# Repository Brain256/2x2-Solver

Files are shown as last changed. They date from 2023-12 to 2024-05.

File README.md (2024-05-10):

# 2x2-Solver

https://www.youtube.com/shorts/pykEr9slMbM

This is a repository containing information on my Arduino 2x2 Rubik's cube solver 

## Hardware

This 2x2 solver utilizes my computer's webcam to gather data on the 2x2 Rubik's cube sides. It also utilizes an Arduino Uno microcontroller which is connected to a stepper motor and servo motor, which rotate the cube and flip the cube respectively. The program utilizes serial communication between my computer and the Arduino with a USB cable. 

## Design 

The 2x2 solver is made with a stepper motor attached to a cube holder allowing the cube to be rotated along the x-axis and uses a servo motor connected to a flipping arm that hits the cube from the bottom to flip the cube along the y-axis. To perform an actual turn of the 2x2 on just the top half, on the top part of the flipping arm there are 2 beams to hold the top half in place by turning the servo the opposite way to the flipping function while the bottom half is turned by the stepper motor. This combination of flipping and turning allows the 2x2 to be turned on any face.

## Program 

The 2x2 solver algorithm uses 2 separate programs, one on my computer in Python on VS code with another running on the Arduino. The Arduino program waits for serial signals given by the Python program on my computer and using those signals, adjusts the servo and stepper motors to perform turning, rotations, and flipping. The Python program is where the algorithm to solve the cube is created. The program first utilizes the Opencv library to create colour masks of the 4 pieces of every side to find the colour of each piece. The webcam colour information is stored in a 2d array, which represents the cube with each subarray containing the colour of each piece in each face of the cube. The 2d array representation of the cube is manipulated through the rotateCube function which moves the elements of the 2d array using specific Rubik's cube notation as can be seen here (https://ruwix.com/the-rubiks-cube/notation/). For simplicity, only 6 moves are implemented as the other moves can be performed from this set of 6 on the 2x2. The solution to solve the Rubik's cube is in the form of an array of these moves "R", "U", "F", "X", "Y", "Z". The Arduino is sent these individual characters and its program then performs different actions with the motors based on the move. 

## Algorithm to solve the cube

The algorithm to solve the cube is a Python version of the 2x2 speedcubing method Ortega as can be read here (https://kewbz.com/pages/2x2-ortega-method-full-algs-guide)

### First Face

The actual solution to solve the cube starts by solving the first face. The program utilizes a bfs approach to solve the first face performing every possible move in every possible order until it solves the first face. Due to the small size of the 2x2, this brute force is feasible not taking too much time to find a solution. The bfs function returns the sequence of moves to successfully solve the first face in the form of an array that will eventually store the whole solution. 

### Top face and last 2 layers

In order to solve the opposite face of the cube, a long series of if statements is used to check for each of the 7 possible cases and append its corresponding sequence of moves to solve that case to the solution array. Since the solutions utilize the full Rubik's cube notation, I created a function, parseToMachine, to convert the algorithm to all "R", "U", and "F" moves. Following finishing the top face, the 2 last layers are finished in a similar manner checking for all the cases and adding it on to the solution array. 

Once the array containing the solution is completed, it is split and each move is sent to the Arduino to physically turn the cube and solve it.

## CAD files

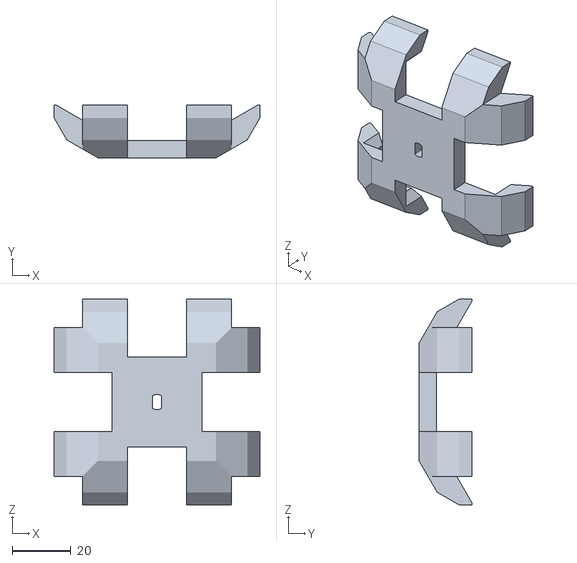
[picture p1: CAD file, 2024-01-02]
models/2x2_Bottom_Turner.stl
70.0 x 18.0 x 70.0

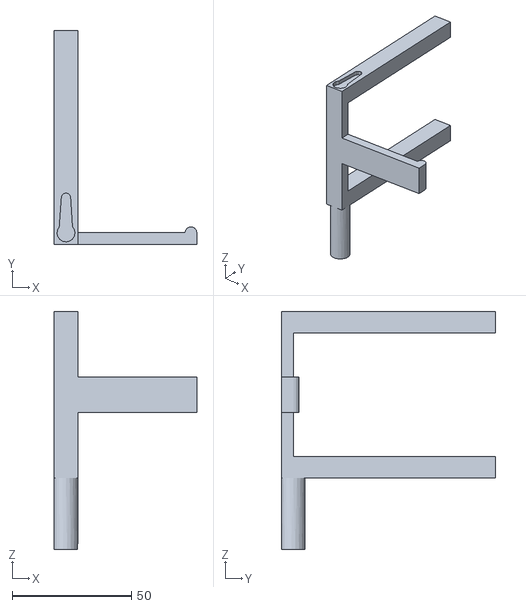
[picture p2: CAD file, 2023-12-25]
models/Solver_Attachment.stl
60.0 x 90.0 x 100.0

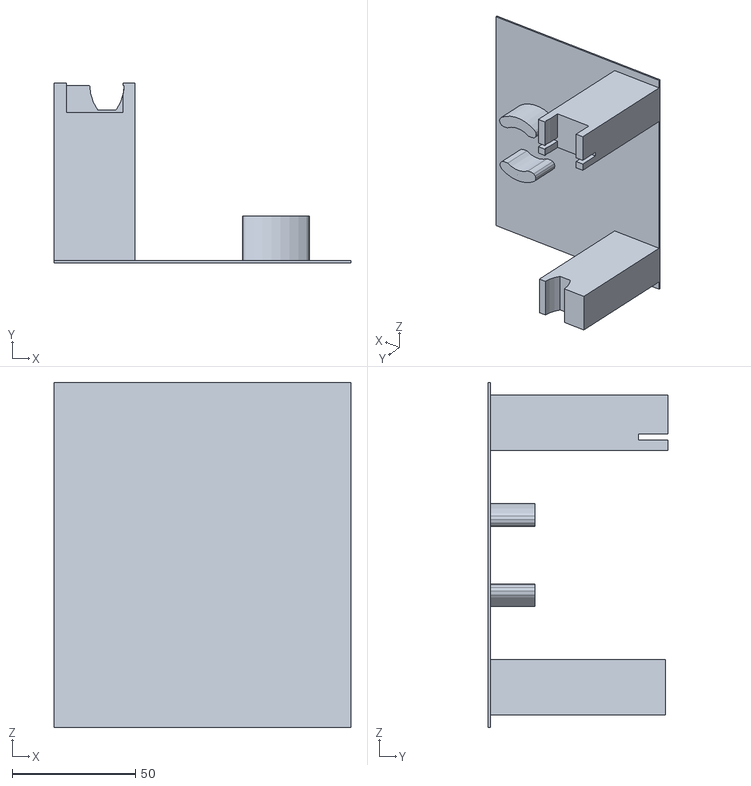
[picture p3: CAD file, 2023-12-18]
models/Solver_Base.stl
120.3 x 73.0 x 140.0

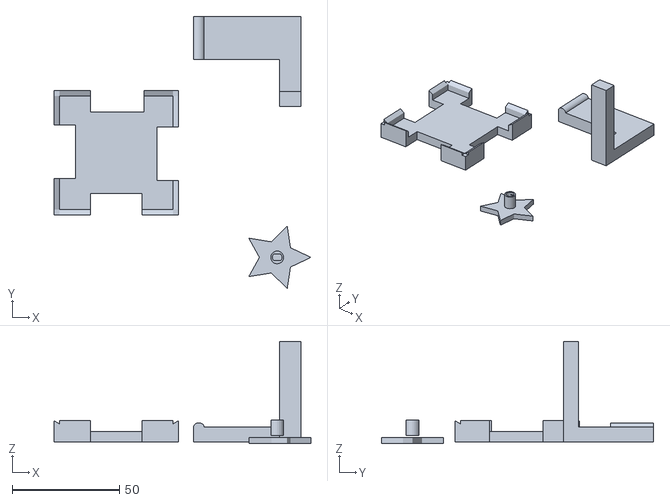
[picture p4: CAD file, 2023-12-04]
models/2x2Solver (4).stl
119.8 x 126.8 x 47.8

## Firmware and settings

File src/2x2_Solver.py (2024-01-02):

#import necessary libraries
import cv2
import time
import numpy as np
from collections import deque
import serial

def createFace(x, y, width):
    ROI = [x, y, x + width, y + width]
    
    ROI_tl = [ROI[0], ROI[1], ROI[0] + width/2, ROI[1] + width/2]
    ROI_tr = [ROI[0] + width/2, ROI[1], ROI[0] + width, ROI[1] + width/2]
    ROI_bl = [ROI[0], ROI[1] + width/2, ROI[0] + width/2, ROI[1] + width]
    ROI_br = [ROI[0] + width/2, ROI[1] + width/2, ROI[0] + width, ROI[1] + width]

    ROI_tl = list(map(int, ROI_tl))
    ROI_bl = list(map(int, ROI_bl))
    ROI_tr = list(map(int, ROI_tr))
    ROI_br = list(map(int, ROI_br))
    
    ROI = [ROI_tl, ROI_tr, ROI_bl, ROI_br]
    
    return ROI

def rotateCube(move, faces, times):

    faces = [face.copy() for face in faces]

    for i in range(times):   
        if move == "R":
            face_nums = [2]
            f = [1, 5, 3, 4]
            p1_index = 1
            p2_index = 3
            
            temp1 = faces[1][p1_index]
            temp2 = faces[1][p2_index]
            
            faces[1][p1_index] = faces[5][p1_index]
            faces[1][p2_index] = faces[5][p2_index]
            
            faces[5][p1_index] = faces[3][2]
            faces[5][p2_index] = faces[3][0]
            
            faces[3][2] = faces[4][p1_index]
            faces[3][0] = faces[4][p2_index]
            
            faces[4][p1_index] = temp1
            faces[4][p2_index] = temp2
            
        if move == "U":

            face_nums = [4]
            f = [1, 2, 3, 0]
            p1_index = 0
            p2_index = 1
            
            p1 = faces[f[0]][p1_index]
            p2 = faces[f[0]][p2_index]
            
            for i in range(3):
                faces[f[i]][p1_index] = faces[f[i+1]][p1_index]
                faces[f[i]][p2_index] = faces[f[i+1]][p2_index]
            
            faces[f[3]][p1_index] = p1
            faces[f[3]][p2_index] = p2
        
        if move == "F":
            face_nums = [1]
            
            temp1 = faces[4][2]
            temp2 = faces[4][3]
            
            faces[4][2] = faces[0][3]
            faces[4][3] = faces[0][1]
            
            faces[0][3] = faces[5][1]
            faces[0][1] = faces[5][0]
            
            faces[5][1] = faces[2][0]
            faces[5][0] = faces[2][2]
            
            faces[2][0] = temp1
            faces[2][2] = temp2

        if move == "X": 
            face_nums = [0, 2]
            
            f = [1, 5, 3, 4]
            
            p = faces[f[0]].copy()
            
            for i in range(3):
                if i == 2: 
                    faces[3][0] = faces[4][3]
                    faces[3][1] = faces[4][2]
                    faces[3][2] = faces[4][1]
                    faces[3][3] = faces[4][0]
                elif i + 1 == 2: 
                    faces[5][0] = faces[3][3]
                    faces[5][1] = faces[3][2]
                    faces[5][2] = faces[3][1]
                    faces[5][3] = faces[3][0]
                    
                else: 
                    faces[f[i]] = faces[f[i+1]].copy()
            
            faces[f[3]] = p

        if move == "Y": 
            face_nums = [4, 5]

            f = [1, 2, 3, 0]
            
            p = faces[f[0]].copy()
            
            for i in range(3):
                faces[f[i]] = faces[f[i+1]]
            
            faces[f[3]] = p

        if move == "Z": 
            face_nums = [1, 3]
            
            f = [2, 4, 0, 5]
            
            p = faces[f[0]].copy()

            for i in range(3):
                faces[f[i]][0] = faces[f[i+1]][2]
                faces[f[i]][1] = faces[f[i+1]][0]
                faces[f[i]][2] = faces[f[i+1]][3]
                faces[f[i]][3] = faces[f[i+1]][1]

            faces[f[3]][0] = p[2]
            faces[f[3]][1] = p[0]
            faces[f[3]][2] = p[3]
            faces[f[3]][3] = p[1]

            
        for face_num in face_nums: 
            if face_num == 3 or face_num == 0: 
                temp = faces[face_num][2]
                
                faces[face_num][2] = faces[face_num][0]
                faces[face_num][0] = faces[face_num][1]
                faces[face_num][1] = faces[face_num][3]
                faces[face_num][3] = temp

            else: 
                temp = faces[face_num][2]
                
                faces[face_num][2] = faces[face_num][3]
                faces[face_num][3] = faces[face_num][1]
                faces[face_num][1] = faces[face_num][0]
                faces[face_num][0] = temp

    return faces

def checkSolvedTB(faces): 

    for i, face in enumerate(faces): 
        if i == 4 or i == 5: 
            col = face[0]
            for piece in face: 
                if piece != col: 
                    return False

    return True

def checkSolvedRL(faces): 

    for i, face in enumerate(faces): 
        if i == 2 or i == 0: 
            col = face[0]
            for piece in face: 
                if piece != col: 
                    return False

    return True

def checkSolvedFB(faces): 

    for i, face in enumerate(faces): 
        if i == 3 or i == 1: 
            col = face[0]
            for piece in face: 
                if piece != col: 
                    return False

    return True

def checkSolved(faces): 

    for i, face in enumerate(faces): 
            col = face[0]
            for piece in face: 
                if piece != col: 
                    return False

    return True

def scramble(move_list, faces): 

    for move in move_list: 
        
        faces = rotateCube(move[0], faces, int(move[1]))

    return faces

def process(move_list): 

    for i in range(len(move_list)): 

        if len(move_list[i]) == 1: 
            move_list[i] += "1"

        if move_list[i][1] == "'": 
            move_list[i] = move_list[i][0] + "3"


def solveTB(queue):

    while len(queue) > 0:
        
        cur = queue.popleft()
        move_list = cur[0]
        faces = cur[1]

        #print(queue)

        if len(move_list) > 11:
            break

        print(move_list)
        
        faces = rotateCube(move_list[-1][0], faces, int(move_list[-1][1]))
        #print(faces)
        
        if checkSolved(faces) or checkSolvedTB(faces) or checkSolvedRL(faces) or checkSolvedFB(faces): 
            return move_list, faces

        for move in moves:
            for i in range(3):
                moveTemp = move_list.copy()
                if move != move_list[-1][0]:
                    moveTemp.append(move + str(i+1))
                    
                    queue.append([moveTemp, faces])

    return []

def solvePBL(result, cube): 
    if checkSolvedRL(cube): 
        #orient cube so solved faces are on top and bottom
        result.append("Z1")
        cube = rotateCube("Z", cube, 1)
    
    elif checkSolvedFB(cube):
        #orient cube so solved faces are on top and bottom
        result.append("X1")
        cube = rotateCube("X", cube, 1)

    algorithm = []
    #both layers solved
    if (cube[0][2] == cube[0][3] and cube[1][2] == cube[1][3] and cube[2][2] == cube[2][3] and cube[3][2] == cube[3][3]) and (cube[0][0] == cube[0][1] and cube[1][0] == cube[1][1] and cube[2][0] == cube[2][1] and cube[3][0] == cube[3][1]): 
        pass
    #bottom layer solved
    elif cube[0][2] == cube[0][3] and cube[1][2] == cube[1][3] and cube[2][2] == cube[2][3] and cube[3][2] == cube[3][3]: 
        #bar on top layer
        if cube[0][0] == cube[0][1] or cube[1][0] == cube[1][1] or cube[2][0] == cube[2][1] or cube[3][0] == cube[3][1]:
            
            if cube[1][0] == cube[1][1]: 
                result.append("Y1")
                cube = rotateCube("Y", cube, 1)
            elif cube[2][0] == cube[2][1]:
                result.append("Y2")
                cube = rotateCube("Y", cube, 2)
            elif cube[3][0] == cube[3][1]: 
                result.append("Y3")
                cube = rotateCube("Y", cube, 3)

            algorithm = "R U R' U' R' F R2 U' R' U' R U R' F'".split()
        else:
            algorithm = "F R U' R' U' R U R' F' R U R' U' R' F R F'".split()

    #top layer solved
    elif cube[0][0] == cube[0][1] and cube[1][0] == cube[1][1] and cube[2][0] == cube[2][1] and cube[3][0] == cube[3][1]: 
        #bar on bottom layer
        if cube[0][2] == cube[0][3] or cube[1][2] == cube[1][3] or cube[2][2] == cube[2][3] or cube[3][2] == cube[3][3]:
            if cube[1][2] == cube[1][3]: 
                result.append("Y1")
                cube = rotateCube("Y", cube, 1)
            elif cube[2][2] == cube[2][3]:
                result.append("Y2")
                cube = rotateCube("Y", cube, 2)
            elif cube[3][2] == cube[3][3]: 
                result.append("Y3")
                cube = rotateCube("Y", cube, 3)

            algorithm = "R' U R' U' R' F R2 U' R' U' R U R' F' R2".split()
        else:
            result.append("X2")
            cube = rotateCube("X", cube, 2)

            algorithm = "F R U' R' U' R U R' F' R U R' U' R' F R F'".split()
    #bars on both layers
    elif (cube[0][2] == cube[0][3] or cube[1][2] == cube[1][3] or cube[2][2] == cube[2][3] or cube[3][2] == cube[3][3]) and (cube[0][0] == cube[0][1] or cube[1][0] == cube[1][1] or cube[2][0] == cube[2][1] or cube[3][0] == cube[3][1]): 
        if cube[0][2] == cube[0][3]: 
            result.append("Y3")
            cube = rotateCube("Y", cube, 3)
        elif cube[2][2] == cube[2][3]:
            result.append("Y1")
            cube = rotateCube("Y", cube, 1)
        elif cube[3][2] == cube[3][3]: 
            result.append("Y2")
            cube = rotateCube("Y", cube, 2)

        if cube[0][0] == cube[0][1]: 
            result.append("U3")
            cube = rotateCube("U", cube, 3)
        elif cube[2][0] == cube[2][1]:
            result.append("U1")
            cube = rotateCube("U", cube, 1)
        elif cube[3][0] == cube[3][1]: 
            result.append("U2")
            cube = rotateCube("U", cube, 2)
        
        algorithm = "R2 U' F2 U2 R2 U' F2".split()

    #bar on bottom layer
    elif cube[0][2] == cube[0][3] or cube[1][2] == cube[1][3] or cube[2][2] == cube[2][3] or cube[3][2] == cube[3][3]: 
        result.append("Z2")
        cube = rotateCube("Z", cube, 2)

        if cube[0][0] == cube[0][1]: 
            result.append("Y3")
            cube = rotateCube("Y", cube, 3)
        elif cube[2][0] == cube[2][1]:
            result.append("Y1")
            cube = rotateCube("Y", cube, 1)
        elif cube[3][0] == cube[3][1]: 
            result.append("Y2")
            cube = rotateCube("Y", cube, 2)
        
        algorithm = "R U' R F2 R' U R'".split()

    #bar on top layer
    elif cube[0][0] == cube[0][1] or cube[1][0] == cube[1][1] or cube[2][0] == cube[2][1] or cube[3][0] == cube[3][1]: 
        if cube[0][0] == cube[0][1]: 
            result.append("Y3")
            cube = rotateCube("Y", cube, 3)
        elif cube[2][0] == cube[2][1]:
            result.append("Y1")
            cube = rotateCube("Y", cube, 1)
        elif cube[3][0] == cube[3][1]: 
            result.append("Y2")
            cube = rotateCube("Y", cube, 2)
        
        algorithm = "R U' R F2 R' U R'".split()

    else: 
        algorithm = "R2 F2 R2".split()

    process(algorithm)
    cube = scramble(algorithm, cube)
    result.extend(algorithm)

    #auf
    if not checkSolved(cube): 
        if cube[1][0] == cube[0][2]:
            result.append("U1")
            cube = rotateCube("U", cube, 1)
        elif cube[2][0] == cube[0][2]: 
            result.append("U2")
            cube = rotateCube("U", cube, 2)
        elif cube[3][0] == cube[0][2]: 
            result.append("U3")
            cube = rotateCube("U", cube, 3)

    return cube

def parseToMachine(moveList): #turns the generated solution into a solution that the robot can use since the robot can only use X, Y and D moves, assumes that the front of the cube is facing the flipper
    newMoves = []

    for move in moveList: 
        if move[0] == "R": 
            newMoves.extend(f"Y3 X1 D{move[1]} X3 Y1".split())
        elif move[0] == "U": 
            newMoves.extend(f"D{move[1]} Y{move[1]}".split())
        elif move[0] == "F": 
            newMoves.extend(f"X3 D{move[1]} X1".split())
        elif move[0] == "Z": 
            newMoves.extend(f"Y3 X{move[1]} Y1".split()) 
        else: 
            newMoves.append(move)
    
    print(newMoves)

    length = len(newMoves) - 1
    i = 0

    while i < length:
        if newMoves[i][0] == newMoves[i+1][0]:
            num = (int(newMoves[i][1]) + int(newMoves[i+1][1])) % 4

            if num == 0:
                newMoves.pop(i)
                newMoves.pop(i)
                length -= 2
                i -= 1
            else:
                newMoves.pop(i+1)
                newMoves[i] = newMoves[i][0] + str(num)
                length -= 1
                i -= 1

        i += 1


    return newMoves

    
moves = ["R", "U", "F"]
    

ROI_tl = createFace(220, 140, 200)[0]
ROI_tr = createFace(220, 140, 200)[1]
ROI_bl = createFace(220, 140, 200)[2]
ROI_br = createFace(220, 140, 200)[3]

#0 - Left, 1 - front, 2 - right, 3 - back, 4 - top, 5 - bottom
curFace = 0

face_left = createFace(10, 70, 50)
face_front = createFace(70, 70, 50)
face_right = createFace(130, 70, 50)
face_back = createFace(190, 70, 50)
face_top = createFace(70, 10, 50)
face_bottom = createFace(70, 130, 50)

faceDisplay = [face_left, face_front, face_right, face_back, face_top, face_bottom]
faceColours = [[], [], [], [], [], []]

colours = ["orange", "red", "green", "blue", "white", "yellow"]

#colour codes in BGR
colCodes = [
    (0, 165, 255),   # Orange
    (0, 0, 255),     # Red
    (0, 255, 0),     # Green
    (255, 0, 0),     # Blue
    (255, 255, 255), # White
    (0, 255, 255)    # Yellow
]

#0 for orange, 1 for red, 2 for green, 3 for blue, 4 for white, 5 for yellow
quadColours = [0, 0, 0, 0]

for i in range(6): 
    faceColours[i] = quadColours.copy()

startTime = 0
curTime = time.time()

cam = cv2.VideoCapture(0)

beginTime = False
sGenerated = False
result = []

ser = serial.Serial('COM5', 115200)

seq = [['Y1'], ['Y1'], ['Y1'], ['Y2', 'X1'], ['X2'], ['X1, Y2']]

#main loop
while True:
    
    #get an image from pi camera
    res, img = cam.read()

    if not beginTime: 
        startTime = time.time()
        beginTime = True 

    curTime = time.time()
        
    if curTime - startTime > 3:
        if curFace != 6:
            curFace += 1

            for move in seq[curFace-1]: 
                time.sleep(1)
                print(move)
                ser.write(move.encode())

                while True: 

                    data = ser.readline().decode('utf-8').rstrip()

                    if data == "done":
                        print("move finished")
                        break
                    
            startTime = time.time()
    
    if curFace != 6: 
    
        # convert from BGR to HSV
        img_hsv = cv2.cvtColor(img, cv2.COLOR_BGR2HSV)
        
        # orange mask
        lower_orange = np.array([7, 90, 172])
        upper_orange = np.array([16, 255, 255])

        o_mask = cv2.inRange(img_hsv, lower_orange, upper_orange)
        
        #create red mask
        lower_red = np.array([0, 110, 155])
        upper_red = np.array([6, 255, 255])
        
        r_mask = cv2.inRange(img_hsv, lower_red, upper_red)
        
        #create green mask
        lower_green = np.array([43, 0, 120])
        upper_green = np.array([88, 255, 255])

        g_mask = cv2.inRange(img_hsv, lower_green, upper_green)
        
        #create blue mask
        lower_blue = np.array([92, 120, 110])
        upper_blue = np.array([110, 255, 255])

        b_mask = cv2.inRange(img_hsv, lower_blue, upper_blue)
        #create white mask
        lower_white = np.array([0, 0, 120])
        upper_white = np.array([180, 50, 255])

        w_mask = cv2.inRange(img_hsv, lower_white, upper_white)
        
        #create yellow mask
        lower_yellow = np.array([16, 90, 160])
        upper_yellow = np.array([40, 255, 255])

        y_mask = cv2.inRange(img_hsv, lower_yellow, upper_yellow)
        
        #ORANGE
        o_cont_tl = cv2.findContours(o_mask[ROI_tl[1]:ROI_tl[3], ROI_tl[0]:ROI_tl[2]], cv2.RETR_EXTERNAL, cv2.CHAIN_APPROX_SIMPLE)[-2]
        o_cont_tr = cv2.findContours(o_mask[ROI_tr[1]:ROI_tr[3], ROI_tr[0]:ROI_tr[2]], cv2.RETR_EXTERNAL, cv2.CHAIN_APPROX_SIMPLE)[-2]
        o_cont_bl = cv2.findContours(o_mask[ROI_bl[1]:ROI_bl[3], ROI_bl[0]:ROI_bl[2]], cv2.RETR_EXTERNAL, cv2.CHAIN_APPROX_SIMPLE)[-2]
        o_cont_br = cv2.findContours(o_mask[ROI_br[1]:ROI_br[3], ROI_br[0]:ROI_br[2]], cv2.RETR_EXTERNAL, cv2.CHAIN_APPROX_SIMPLE)[-2]
        
        #RED
        r_cont_tl = cv2.findContours(r_mask[ROI_tl[1]:ROI_tl[3], ROI_tl[0]:ROI_tl[2]], cv2.RETR_EXTERNAL, cv2.CHAIN_APPROX_SIMPLE)[-2]
        r_cont_tr = cv2.findContours(r_mask[ROI_tr[1]:ROI_tr[3], ROI_tr[0]:ROI_tr[2]], cv2.RETR_EXTERNAL, cv2.CHAIN_APPROX_SIMPLE)[-2]
        r_cont_bl = cv2.findContours(r_mask[ROI_bl[1]:ROI_bl[3], ROI_bl[0]:ROI_bl[2]], cv2.RETR_EXTERNAL, cv2.CHAIN_APPROX_SIMPLE)[-2]
        r_cont_br = cv2.findContours(r_mask[ROI_br[1]:ROI_br[3], ROI_br[0]:ROI_br[2]], cv2.RETR_EXTERNAL, cv2.CHAIN_APPROX_SIMPLE)[-2]
        
        #GREEN
        g_cont_tl = cv2.findContours(g_mask[ROI_tl[1]:ROI_tl[3], ROI_tl[0]:ROI_tl[2]], cv2.RETR_EXTERNAL, cv2.CHAIN_APPROX_SIMPLE)[-2]
        g_cont_tr = cv2.findContours(g_mask[ROI_tr[1]:ROI_tr[3], ROI_tr[0]:ROI_tr[2]], cv2.RETR_EXTERNAL, cv2.CHAIN_APPROX_SIMPLE)[-2]
        g_cont_bl = cv2.findContours(g_mask[ROI_bl[1]:ROI_bl[3], ROI_bl[0]:ROI_bl[2]], cv2.RETR_EXTERNAL, cv2.CHAIN_APPROX_SIMPLE)[-2]
        g_cont_br = cv2.findContours(g_mask[ROI_br[1]:ROI_br[3], ROI_br[0]:ROI_br[2]], cv2.RETR_EXTERNAL, cv2.CHAIN_APPROX_SIMPLE)[-2]
        
        #BLUE
        b_cont_tl = cv2.findContours(b_mask[ROI_tl[1]:ROI_tl[3], ROI_tl[0]:ROI_tl[2]], cv2.RETR_EXTERNAL, cv2.CHAIN_APPROX_SIMPLE)[-2]
        b_cont_tr = cv2.findContours(b_mask[ROI_tr[1]:ROI_tr[3], ROI_tr[0]:ROI_tr[2]], cv2.RETR_EXTERNAL, cv2.CHAIN_APPROX_SIMPLE)[-2]
        b_cont_bl = cv2.findContours(b_mask[ROI_bl[1]:ROI_bl[3], ROI_bl[0]:ROI_bl[2]], cv2.RETR_EXTERNAL, cv2.CHAIN_APPROX_SIMPLE)[-2]
        b_cont_br = cv2.findContours(b_mask[ROI_br[1]:ROI_br[3], ROI_br[0]:ROI_br[2]], cv2.RETR_EXTERNAL, cv2.CHAIN_APPROX_SIMPLE)[-2]
        
        #WHITE
        w_cont_tl = cv2.findContours(w_mask[ROI_tl[1]:ROI_tl[3], ROI_tl[0]:ROI_tl[2]], cv2.RETR_EXTERNAL, cv2.CHAIN_APPROX_SIMPLE)[-2]
        w_cont_tr = cv2.findContours(w_mask[ROI_tr[1]:ROI_tr[3], ROI_tr[0]:ROI_tr[2]], cv2.RETR_EXTERNAL, cv2.CHAIN_APPROX_SIMPLE)[-2]
        w_cont_bl = cv2.findContours(w_mask[ROI_bl[1]:ROI_bl[3], ROI_bl[0]:ROI_bl[2]], cv2.RETR_EXTERNAL, cv2.CHAIN_APPROX_SIMPLE)[-2]
        w_cont_br = cv2.findContours(w_mask[ROI_br[1]:ROI_br[3], ROI_br[0]:ROI_br[2]], cv2.RETR_EXTERNAL, cv2.CHAIN_APPROX_SIMPLE)[-2]
        
        #YELLOW
        y_cont_tl = cv2.findContours(y_mask[ROI_tl[1]:ROI_tl[3], ROI_tl[0]:ROI_tl[2]], cv2.RETR_EXTERNAL, cv2.CHAIN_APPROX_SIMPLE)[-2]
        y_cont_tr = cv2.findContours(y_mask[ROI_tr[1]:ROI_tr[3], ROI_tr[0]:ROI_tr[2]], cv2.RETR_EXTERNAL, cv2.CHAIN_APPROX_SIMPLE)[-2]
        y_cont_bl = cv2.findContours(y_mask[ROI_bl[1]:ROI_bl[3], ROI_bl[0]:ROI_bl[2]], cv2.RETR_EXTERNAL, cv2.CHAIN_APPROX_SIMPLE)[-2]
        y_cont_br = cv2.findContours(y_mask[ROI_br[1]:ROI_br[3], ROI_br[0]:ROI_br[2]], cv2.RETR_EXTERNAL, cv2.CHAIN_APPROX_SIMPLE)[-2]
        
        tl = [o_cont_tl, r_cont_tl, g_cont_tl, b_cont_tl, w_cont_tl, y_cont_tl]
        tr = [o_cont_tr, r_cont_tr, g_cont_tr, b_cont_tr, w_cont_tr, y_cont_tr]
        bl = [o_cont_bl, r_cont_bl, g_cont_bl, b_cont_bl, w_cont_bl, y_cont_bl]
        br = [o_cont_br, r_cont_br, g_cont_br, b_cont_br, w_cont_br, y_cont_br]
        
        max_tl_area = 0
        max_tr_area = 0
        max_bl_area = 0
        max_br_area = 0
        
        for i in range(len(tl)):
            if tl[i]:
                for cont in tl[i]:
                    area = cv2.contourArea(cont)
                    
                    if area > max_tl_area:
                        max_tl_area = area
                        quadColours[0] = i
                    
                    #print(area)
                        
        for i in range(len(tr)):
            if tr[i]:
                for cont in tr[i]:
                    area = cv2.contourArea(cont)
                    
                    if area > max_tr_area:
                        max_tr_area = area
                        quadColours[1] = i
                    
                    #print(area)
        
        for i in range(len(bl)):
            if bl[i]:
                for cont in bl[i]:
                    area = cv2.contourArea(cont)
                    
                    if area > max_bl_area:
                        max_bl_area = area
                        quadColours[2] = i
                    
                    #print(area)
                        
        for i in range(len(br)):
            if br[i]:
                for cont in br[i]:
                    area = cv2.contourArea(cont)
                    
                    if area > max_br_area:
                        max_br_area = area
                        quadColours[3] = i
                    
                    #print(area)

        faceColours[curFace] = quadColours.copy()
        #img = img_hsv

    
    elif not sGenerated:
        
        sTime = time.time()
        queue = deque([])

        if checkSolved(faceColours):
            print("already solved")
            sGenerated = True
            continue
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

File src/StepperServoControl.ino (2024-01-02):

#include <Stepper.h>
#include <Servo.h>

Servo myservo;

const int stepsPerRevolution = 2048;

Stepper myStepper = Stepper(stepsPerRevolution, 8, 10, 9, 11);

char move[3];

void setup() {
  Serial.begin(115200);

  myservo.attach(5); 
  myservo.write(113); 

}

void loop() {

  while(Serial.available() > 0)
  {

    int size = Serial.readBytes(move, 2);
    move[2] = '\0';

    if(move[0] == 'D')
    {
      myservo.write(140); 
      delay(500); 
      if(move[1] == '1') {
        myStepper.setSpeed(13);
	      myStepper.step(stepsPerRevolution/4 + 40);
      } else if(move[1] == '2') {
        myStepper.setSpeed(13);
	      myStepper.step(stepsPerRevolution/2 + 40);
      } else {
        myStepper.setSpeed(13);
	      myStepper.step(-stepsPerRevolution/4 - 40);
      }
      delay(500); 
      myservo.write(113); 
      
      if(move[1] == '1') {
        myStepper.setSpeed(13);
	      myStepper.step(-40);
      } else if(move[1] == '2') {
        myStepper.setSpeed(13);
	      myStepper.step(-40);
      } else {
        myStepper.setSpeed(13);
	      myStepper.step(40);
      }

      delay(500); 
      
    } else if(move[0] == 'X') {

      for(int i = 0; i < move[1] - '0'; i++) {

        myservo.write(72); 
        delay(300); 
        myservo.write(113); 
        delay(500);
      }

    } else if(move[0] == 'Y') {

      if(move[1] == '1') {
        myStepper.setSpeed(13);
	      myStepper.step(-stepsPerRevolution/4);
      } else if(move[1] == '2') {
        myStepper.setSpeed(13);
	      myStepper.step(-stepsPerRevolution/2);
      } else {
        myStepper.setSpeed(13);
	      myStepper.step(stepsPerRevolution/4);
      }

      delay(500); 
    }

    Serial.println("done");

  }
}

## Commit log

2023-11-11 Update 2x2_Solver.py
    - adjusted color masks
    - the program now prints the color of each corner in the current face in the ROI
2023-11-11 Update 2x2_Solver.py
    -now displays current colours of each face in top left corner
    -only one face shows in all 6 faces for now
2023-11-11 Update 2x2_Solver.py
    -all 6 faces can now be enrolled
    -added a timer so that every 5 seconds a new face is added
2023-11-15 version 1 of 3d model
    [2x2Solver.obj]
2023-11-15 Delete 2x2Solver.obj
    gonna replace with stl
    [2x2Solver.obj]
2023-11-15 3d model stl file type
    [2x2Solver.stl]
2023-11-19 added motors
2023-11-19 idk how to replace a file so im deleting and adding a new one
    [2x2Solver.stl]
2023-11-19 Added servo attachment hole thing
    [2x2Solver (1).stl]
2023-11-26 added testSolver.py
    file is used for testing the solving algorithm on my computer before being put on raspberry pi
2023-11-30 adjusted code and colour masks to work on PC as raspberry pi is too slow
    [2x2_Solver.py]
2023-12-02 added file which controls stepper motor with serial communication
2023-12-03 Added serial communication with Arduino
2023-12-03 Added X and Y moves
    - implemented servo
    - added communication with python program
2023-12-03 fixed commands for moves
    [StepperServoControl.ino]
2023-12-04 added/changed stepper motor attachment
    [2x2Solver (2).stl]
2023-12-04 rounded edges
    [2x2Solver (3).stl]
2023-12-04 slope edge
    [2x2Solver (4).stl]
2023-12-17 Update Servo Angle Positions
2023-12-18 Updated Stepper Movement
    - made the motor rotate a little extra and then re align so that the cube will make a full rotation
2023-12-18 moved arduino code into src folder
2023-12-18 moved 2x2Solver (4).stl to src folder
    [2x2Solver (4).stl]
2023-12-18 moved 2x2_Bottom_Turner.stl to models folder
    [2x2_Bottom_Turner.stl]
2023-12-18 added models
    [2x2_Bottom_Turner.stl, 2x2_Robot.stl, Solver_Attachment.stl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]
2023-12-25 made flipping arm a little shorter
    [Solver_Attachment.stl]
2023-12-25 made flipping arm shorter
    [Solver_Attachment.stl]
2023-12-25 Adjusted angle positions of servo and made stepper overturn a bit more
2024-01-02 Adjusted Servo and Stepper positions
2024-01-02 Removed rails in corners
    [2x2_Bottom_Turner.stl]
